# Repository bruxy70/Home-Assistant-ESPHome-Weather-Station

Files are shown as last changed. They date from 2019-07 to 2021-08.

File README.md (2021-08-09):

# Home-Assistant-ESPHome-Weather-Station
Nextion display with ESP8266 microcontroller (Wemos D1 mini) showing Home Assistant temperature sensors (temperature inside, outside and in the swiming pool) and weather forecast from the internet. But you might display any Hassio sensors, so if you wish to create own weather forecast, you can do that.

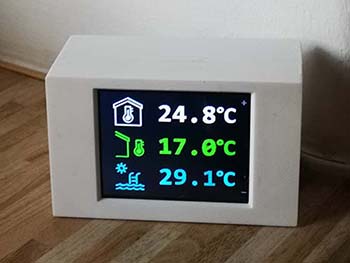
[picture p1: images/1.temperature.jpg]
Temperatures Page 1 - temperature sensors
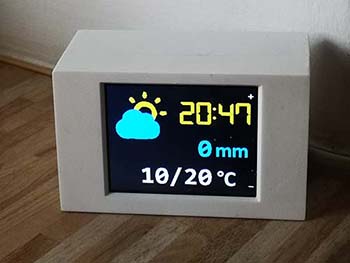
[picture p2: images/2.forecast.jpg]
Forecast Page 2 - weather forecast
  



## Getting Started

### Architecture

The Nextion display is connected via 4 wires: GND, +5V, RX, and TX. So to control the display is extremely easy - just connect these 4 wires to the corresponding ports in an Arduino board and you are set. In this project, I am using Wemos D1 mini. But in some other projects, I have the display connected to Sonoff 4ch or even Sonoff Basic (the only challenge with these is to find the pin with 5V, but this is not that hard).

### Design

The principle is very simple: I used Nextion Editor to create a layout for the display screen. There is a static image background with all graphics that do not change (including text, icons, frames, or color background). On top of the background, I created text or image objects for all the values that change. When the design is finished, you can upload the layout to the display from the NextionEditor using the serial connection (via USB FTDI board).

The program  is then very simple - it just sets the text value for the individual text objects. For example, for the inside temperature it does this:
```
it.set_component_text_printf("inside","%2.1f",id(temperature_inside).state);
```

ESPHome can read Home Assistant sensors through API, so the ESPHome sensor "teplota_uvnitr" is linked to Home Assistant sensor sensor.teplota_uvnitr this way:
```
sensor:
  - platform: homeassistant   # Inside temperature
    id: teperature_inside
    entity_id: sensor.temperature_inside
```

The weather forecast uses a picture - I have loaded set of icons through the NextionEditor, so all I do us to change the picture id this way:
```
it.send_command_printf("%s.pic=%.0f", "weather",id(today_icon).state);
```

For the ESPHome to communicate, the HMI also needs to be configured not to send responses on the commands. It is also a good idea to increase the port speed. To do that, in the Nextion Editor, in the `Program.s` tab, add these two commands before the `page` line.
```
baud=115200
bkcmd=0
```

It is using the [2.4 inch Nextion display](https://www.banggood.com/Nextion-NX3224T024-2_4-Inch-Man-machine-Interface-HMI-Screen-Kernel-In-English-p-1105052.html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).

### Additional features

There are two more "nice to have" features:
1. The display has 2 pages. I made it so it does change the page on each refresh (every 5 seconds). This is optional, you can make it either to show one page only. Or to flip the page on touching the screen (this can be easily done directly from the NextionEditor, without any programming).
2. On my Home Assistant, I also have a sensor showing whether somebody is home. When the alarm is on, nobody is home - so I am turning off the display light. And I only update the information when the display is on. This is entirely optional.
3. I also display the internet time, using ESPHome's time service.

### Source files

- **display_weather.yaml** - this is the main file - the actual ESPHome configuration
- **display.HMI** - this is the actual design of the display I use - the file can be edited via the NextionEditor (can be [downloaded](https://nextion.itead.cc/resources/download/nextion-editor/) from ITEAD pages)
- **weather.yaml** - Home Assistant configuration of the weather sensors I use. You can obviously use any sensors or any other weather service you like. Additionally, I have 3 temperature sensors - one of them is Z-Wave temperature sensor (internal). The other sensors are created through ESPHome. I also have luminosity sensor and rain sensor (but I do not show these, they are used in various automations). It is really up to you what information you find useful to show.
- **images (folder)** - I have included the source images for the Nextion display editor. These are not essential for the project, but if you want to create own design, you can start from there.
- **3D model front.stl, 3D model back.stl** - 3D model of the box the display is mounted in (Wemos D1 mini fits in the back).

## Author

* **Václav Chaloupka** - *Initial work* - [bruxy70](https://github.com/bruxy70)

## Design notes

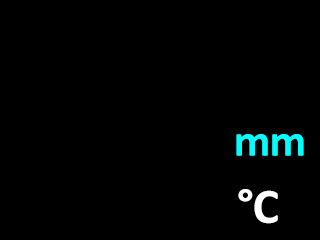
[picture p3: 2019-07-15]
images/Nextion forecast.tif

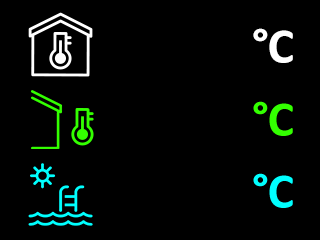
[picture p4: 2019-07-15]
images/Nextion - teplota.tif

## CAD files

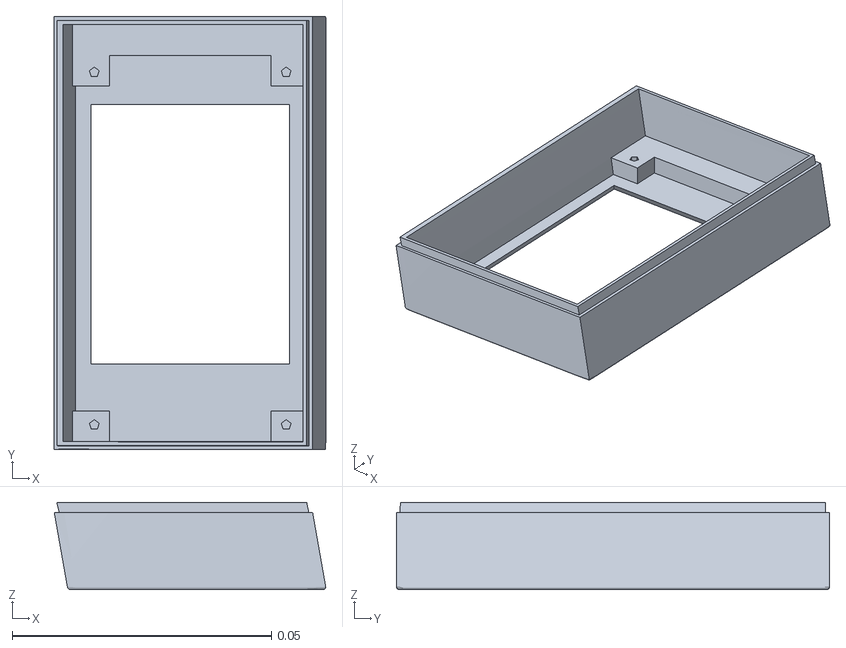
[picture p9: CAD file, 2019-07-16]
3d model src/krabicka-celo (52.4 x 83.5 x 16.8 mm).stl
0.0524 x 0.0835 x 0.0168

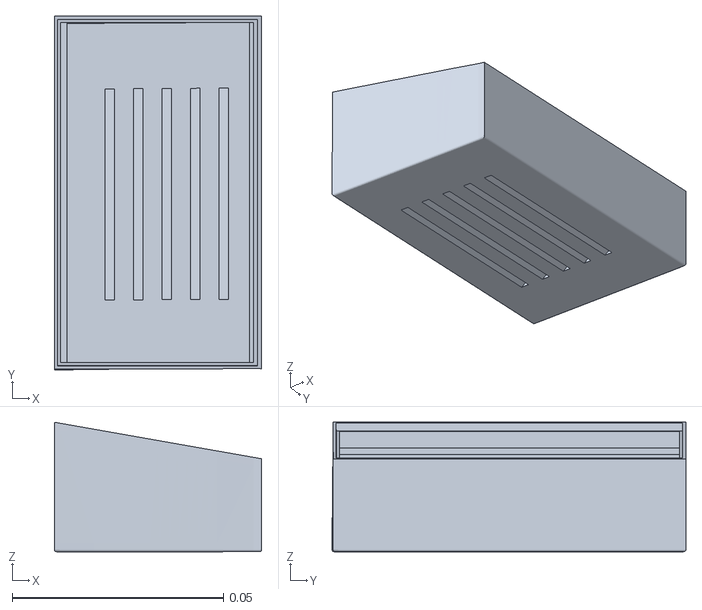
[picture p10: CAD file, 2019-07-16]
3d model src/krabicka-zada (49.1 x 83.8 x 30.7 mm).stl
0.0491 x 0.0838 x 0.0307

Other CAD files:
3d model src/display.blend

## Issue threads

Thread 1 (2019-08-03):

Waiting for ACK timed out!

gijsje, 2019-08-03:
Thank you for the creating this.
I have been playing with my nextion for a long time but am not able to get it to work with any programming.
The only thing i do get is:
```
[14:26:02][W][nextion:036]: Waiting for ACK timed out!
[14:26:02][W][nextion:083]: Sending command 'outside.txt="21.6"' failed because no ACK was received
```

I did change the pins around in the software and physical but nothing works

I am using a 5" display but that should not really care i guess
I also did try with another 2.4 display with the same thing

`# This is ESPHome configuration file. This goes to the esphome folder
# You need to provide your WiFi ssis/password and passwords for API and OTA (or put them in your esphome/secrets.yaml)
esphome:
  name: display_weather
  platform: ESP8266
  board: d1_mini_pro

wifi:
  ssid: SSID
  password: PASS
  fast_connect: true

api:
  password: PASS

ota:
  password: PASS

logger:
  baud_rate: 0     # Disable UART logging (pins GPIO1/3 are used for Nextion communication)

uart:
  rx_pin: D1
  tx_pin: D6
  baud_rate: 9600

time:
  - platform: sntp
    id: sntp_time

sensor:
  - platform: homeassistant   # Inside temperature
    id: temperature_inside
    entity_id: sensor.kantoor_temperatuur

  - platform: homeassistant   # Outside temperature
    id: temperature_outside
    entity_id: sensor.tuin_temperatuur

  - platform: homeassistant   # Swimming pool
    id: temperature_pool
    entity_id: sensor.keuken_koelkast_temperatuur

  - platform: homeassistant   # Forecast minimal temperature
    id: today_min
    entity_id: sensor.today_min

  - platform: homeassistant   # Forecast maximal temperature
    id: today_max
    entity_id: sensor.today_max

  - platform: homeassistant   # Forecast precipitation
    id: today_rain
    entity_id: sensor.today_rain

  - platform: homeassistant   # Forecast icon
    id: today_icon
    entity_id: sensor.today_icon

binary_sensor:
  - platform: homeassistant
    id: somebody_home
    entity_id: binary_sensor.kantoor_beweging

globals:
 - id: first_page             # First page of the display?
   type: bool
   restore_value: no
 - id: display_on             # Is display on?
   type: bool
   restore_value: no

display:
  - platform: nextion
    id: teplomer
    update_interval: 5s
    lambda: |-
      // Turn display on when somebody is home. Only update when display on.
      if (id(somebody_home).state) {
        if (!id(display_on)) {
          it.set_backlight_brightness(50);
          id(display_on)=true;
        }
        // Swich first/second page on each update (every 5 seconds)
        if (id(first_page)) {
          it.goto_page("forecast");
          it.send_command_printf("%s.pic=%.0f", "weather",id(today_icon).state);
          it.set_component_text_printf("minmax","%.0f/%.0f",id(today_min).state,id(today_max).state);
          if (isnan(id(today_rain).state)) {
            it.set_component_text("rain","-");
          } else {
            it.set_component_text_printf("rain","%.0f",id(today_rain).state);
          }
          auto time = id(sntp_time).now();
          it.set_component_text_printf("hour","%02d",time.hour);
          it.set_component_text_printf("minute","%02d",time.minute);
        } else {
          it.goto_page("temperature");
          it.set_component_text_printf("inside","%2.1f",id(temperature_inside).state);
          it.set_component_text_printf("outside","%2.1f",id(temperature_outside).state);
          it.set_component_text_printf("pool","%2.1f",id(temperature_pool).state);
        }
        id(first_page) = !id(first_page);  // Switch page
      } else {
        // Turn off the display if nobody is home.
        if (id(display_on)) {
          it.set_backlight_brightness(0);
          id(display_on)=false;
        }
      }`

bruxy70, 2019-08-25:
Sorry, I missed your message.

I was getting the error as well, but the display worked.
I made a change to the code not to wait for the ack.

> it.set_wait_for_ack(false);

But that won't fix your issue I think. What do you mean by "nothing works". Is the display on?
Try replacing the lambda by something simple first, such as:

lambda: |-
it.set_wait_for_ack(false);
it.set_component_text("inside","test")

What does the display show?

bruxy70, 2019-08-26:
@gijsje , BTW, you are saying that you tried with 5" display - did the Nextion Editor allow you to upload the screen I designed for 2.4" to the 5" screen?

Closed 2019-09-14.

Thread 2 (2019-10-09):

display not updating

osborne82, 2019-10-09:
hi fairly new to the nextion display so unsure if iv done this correctly
flashed d1 mini with the weather yamel no problems
loaded the hmi file into the latest  Nextion Editor and exported a .tfi file which i then flash onto the display again all good so far
now hook up the rx tx and power everything boots up and display powers up but the sensors dont get populated and doesnt flick between the two pages. only thing i can do is press the plus n minus buttons on the screen for brightness.
i added the example sensors to my configuration.yamel they show up in home assistant

i feel iv probably missed something obvious :) but stuck
thanks

bruxy70, 2019-10-09:
Hi. I think that means that the d1 mini and display do not communicate. I'd check if the RX and TX are not swapped (RX on d1 mini should go to TX on the display and vice versa), and that the pin IDs are set correctly. You can then make a simple test - e.g. in the lambda do simply it.set_component_text("inside","TEST"); to see if the communication works - this does not use any sensor data, but static text - once you get that working you can get back to the origina configuration.

osborne82, 2019-10-09:
Thanks played around some more swapping the tx n rx still nothing. I then
used a different display and bingo most of it started working. Although
temperature is saying NAN the second page does infact show time etc.
I'll keep playing but thank you for your time and the project :)

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

Closed 2019-12-05.

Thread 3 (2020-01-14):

using TFT display with spi.

wisesokol, 2020-01-14:
Is it possible to run your project on TFT with spi interface?
I wanted to make weather station by adafruit, but I liked your project more. The display I bought is TFT 2.4 spi touch.

bruxy70, 2020-01-15:
I suppose it is. If your display is supported here https://esphome.io/index.html#display-components
Or you can do that as a custom SPI device? https://esphome.io/custom/spi.html
In any case, you'd have to basically change the whole display part. If you do that, let me know, we can perhaps share that for the others.

beatagerger, 2021-02-12:
Hallo, mit Nextion und Internetwetter habe ich keine Probleme, auch verschiedene Räume kann in Nextion erstellen (Touch) aber wie verbinde ich die Räume mit der Anzeige? (viele ESP8266 mit eigenen Nextion zu eine grpße "Zentral-Display")?

bruxy70, 2021-02-12:
The display communicates with the microcontroller using UART communication - via 4 wire SPI bus - TX, RX, and 5V.

beatagerger, 2021-02-12:
Hallo bruxy,
ja.
Salon: ESP8266 Wetterstation mit Nextion 3,5 Zoll) (D4) und BME (D1 u D2) Hier auch Wettervorhersage von Openweather
Küche: ESP8266 (DHT)Temperatur/Humidity/Messior(Pflanzen)-Anzeige mit Nextion (2,8 Zoll)
Eingang: ESP8266 (BME) Messer Aussentemperatur/Hum/At
Wintergarten: ESP8266 Temperatur/Humidity-Anzeige.
Aber wie sende ich alle Daten von Küche, Wintergarten & co auf ein einziges Gerät (ESP 32 oder 8266 mit Nextion 7")?????

beatagerger, 2021-02-12:
von 3 oder 4 ESP (Pool Wasser Temperatur von Garten) Daten anzeigen auf ein anderes Gerät, ESP mit Nextion im selben WLAN?

bruxy70, 2021-02-12:
Sorry @beatagerger , I do not speak German. But from what I understand - the individual sensors will pass the temperature/humidity to Home assistant (via API, or MQTT) over WiFi. Or you can use any other sensors, like Zigbee.
Then the ESP32 or 8266 with display will read the values from Home Assistant and display them on the screen. It will not communicate directly to the sensors.

beatagerger, 2021-02-12:
Google übersetzt gut.... hi-hi-hi...
Ich bin zu blöd zu Pi und Pinguin.... Deshalb verwende ich Arduino.
Wie kann man auf ein anderes Gerät per WLAN senden?
Ich habe LED-Strip an ESP8266, diese kann auch GoogleAssistant ein/ausschalten. Aber wie leite ich Daten von einem ESP auf ein andere (ohne ESP-Server)

beatagerger, 2021-02-12:
ich kann auf Thingspeak Daten senden. Das funktioniert gut. Alle Telefonen zeigen es an. Aber der große Nextion nicht.

beatagerger, 2021-02-12:
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

Im Touch (Nextion) kann ich blättern. Das funktioniert. Nur wie mache ich es, wenn ich einen Raum anklicke, dieser Raum wird angezeigt?

beatagerger, 2021-02-12:
Jeder Raum hat seinen eigenen Sensor. Messen, Daten an Thingspeak senden, Online-Wetter (Openwether) funktioniert.
Nur das "Daten sammeln" oder auf ein andere Nextion senden, das funktioniert nicht.

beatagerger, 2021-02-12:
Ich verstehe den ESP-Home nicht.
Würde gerne verwenden, nur wie?
Muss ich etwas auf ESP8266/32 installieren? Wenn ja, was? Ich finde es nicht.
Ist das auch wie Thingspeak? Ein API?

bruxy70, 2021-02-12:
https://esphome.io/components/wifi.html
https://esphome.io/components/api.html

beatagerger, 2021-02-12:
danke.
gerade hier lese ich.
es gibt hier viele Beispiele, aber wie ich einen ESP-Home auf Android mache, finde ich nicht.
ich finde nur, wie ich einen NODEMCU dazu füge
Ist ESP-Home nur für Raspi?

bruxy70, 2021-02-12:
ESPHome is a system to control your ESP8266/ESP32 by simple yet powerful configuration files and control them remotely through Home Automation systems.
https://esphome.io/
I do not think it works for RPi. I do not have any experience with RPi, sorry.

beatagerger, 2021-02-12:
Danke.
Ich möchte keinen Raspi.
Ich weiß aber noch immer nicht welchen Code (Sketch) ich auf ESP laden soll? Und auf welcher Internetseite ist die Einrichtung?
Ich habe in Youtube auch gesucht. (wird immer MQTT gezeigt, also Raspi)
Kannst mir bitte die Internetseite schicken, wo die Einrichtung (Registrieren) erfolgt?

beatagerger, 2021-02-12:
ich habe endlich etwas gefunden.
https://www.youtube.com/watch?v=toANvJKUH3M

Wie installiert man deine Variante? Gibt es dafür einen Sketch auch?

beatagerger, 2021-02-12:
also das war auch nichts... (Server mit Telefon)
Ich hoffe, das bringt mich weiter:
https://community.home-assistant.io/t/home-assistant-community-add-on-visual-studio-code/107863

beatagerger, 2021-02-12:
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
 Endlich!!!!!!!!!!!!!!!!!!!!!!!!!!!!!!
Gefunden!
Jetzt kann ich anfangen!

bruxy70, 2021-02-12:
ESPHome is an addon to Home Assistant. If you do not have Home Assistant, you have to look for another solution.

beatagerger, 2021-02-12:
Bitte!
"Home Assistant"???????????
Alexa?
Google?
Diese kann man mit IFTT kompliiren,
Wie Home Assistant?

beatagerger, 2021-02-12:
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
 diese?

bruxy70, 2021-02-12:
If you want a solution for Alexa or Google, then buy a packaged solution that works with one of these services (they would have their logo on the packaging), and use their display. So to save you some time, you can stop looking in here and look on Amazon instead.

This repo is a DYI project, for people who like that kind of stuff. And for that HA is a great platform, since it is open. And ESPHome is Home Assistant add-on.

beatagerger, 2021-02-12:
Ich habe schon Alexa und auch Google als Assintant. IFTT hilft dabei auch ESP dazu fügen (wenn erwünscht)
Wenn aber meine Geräte und Anzeige damit nicht funktioniert, muss ich andere Lösung suchen.
Bisher war mir ESP Home nicht bekannt. Das ist für mich neu.
Ich weiß nicht,
- wie man es installiert
- wie man es verwenet
- was man damit anfangen kann
deshalb muss ich so viel lesen und experimentieren, bis es das tut, was ich will.
Alle meine Geräte, Sonoff, Tuya & CO habe ich mit Google und Alexa betrieben.

beatagerger, 2021-02-12:
Also HOME ASSINTANT lauft auch auf Android Tablet (13 Zoll)
Aber wie es dennoch auf einen Nextion anzeigt, was ich dort habe will, weiß ich immer noch nicht.............

beatagerger, 2021-02-12:
also. Wenn nicht richtig, biite um Erklärung....
ESP HOME = SERVER (wegen große Datenmengen nicht gut auf NODEMCU, sondern auf Raspi, aber es funktioniert auf ESP32)
ESP HOME ASSISTANT = Verbinden einen NODEMCU mit SERVER (HOME)

Aber!
ASSISTANT schickt Daten an HOME. (das kann man auch auf Google, oder Alexa mit IFTT) ASSISTANT = NODEMCU=Client.

Aber!
Es sollte möglich sein, in einem WLAN viele Client untereinander verbinden können (ohne HOME SERVER)

bruxy70, 2021-02-12:
Not sure I follow.

Home Assistant is an Open Source Home Automation solution. It runs on a number of platforms, including RPi, but also virtual machine or Linux Docker container.

ESPHome is an add-on to Home Assistant. I do not think you can use it without Home Assistant - it compiles the firmware for  ESP8266/ESP32 from Home Assistant, loads it to the micro-controller, and communicates with Home Assistant through Home Assistant API or MQTT.

I understand that you do not have Home Assistant. From your comments, I gather that this is too complicated for you - why should you need Home Assistant - you want to communicate with Alexa directly, or via IFTTT.

And I agree, that having Home Assistant just because of this makes no sense. I have Home Assistant as a central point of my home automation - and there are many reasons why I decided to do that, But you might have different reasons and Home Assistant might not be the best solution for you.

If this is the case, then you came to a wrong place. This solution is based on an integration with Home Assistant. If you do not have it and do not plan to have it, you are just loosing your time here. Drop it and look for other solutions. Maybe Tasmota might be the answer. I do not know, I do not really have an experience with IFTTT or direct integration of DYI solutions with Alexa. Sorry

beatagerger, 2021-02-14:
Hi,
I've been using "assistants" since Cortana, Alexa and Google were around.
I've started with automation for over 15 years, especially with Sonof, because they can operate all "assistants".
My Galusie goes up and down automatically, depending on whether the sun goes up or down. The lights, like Hue, also work great.
I have integrated an LED strip into the ESP 8266. I can also operate it on the Android (it's called "WLED")

My question was because Arduino is to be installed on Windows, but MQTT is more like Ubuntu, don't understand why this is supposed to be?
Raspi is more like Ubuntu, has nothing to do with Arduino.

Anyone can have a "Home Assistant", but in different ways.
I have a NAS, but not from Synergie, and unfortunately I still haven't found anything in years that I could run (where there is also PLEX etc.)
Running a Windows PC 24 hours a day is an exaggeration.

So I prefer Google, Alexa, and CO.
(All devices have their own server, and I just have to make sure that they are compatible with each other. For example, not only Philips lights work with HUE, and the TUYA devices can also be linked to EWELINK or SMARTHOME. ......)
From vacuum cleaner robots to pool pumps, everything runs automatically with us.

But I still haven't figured out what this client, "ESP-HOME Assistant" is for?
What should it connect to? What should it serve?

With TFFT I can also connect any Nodemcu to Google or Alexa. You only have to give a real name instead of having the router assign an IP address (set a fixed IP in the router)
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
beatagerger, 2021-02-14:
Hi,

I think, you misunderstood me.
I have smart home.
I also have 2 ladies who assist me.
I've already automated a lot.
I don't know "ESP HOME", so I read it, I just don't see the point, but maybe because I don't like Ubuntu or Raspery.

Gesendet von Mail<https://go.microsoft.com/fwlink/?LinkId=550986> für Windows 10

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

beatagerger, 2021-02-14:
I still don't know what this is, "HOME ASSISTANT"

Gesendet von Mail<https://go.microsoft.com/fwlink/?LinkId=550986> für Windows 10

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

beatagerger, 2021-02-14:
homeassistant (blue house) can be found in Android, Google Home, Alexa,
aös to install or download as "API" for ESP have not yet found ..........
In IO I only found packages. Not the API or Sketch.
I know that many people are afraid of "their data", so they prefer a server at home ...... I don't .....
I also know that with TASMOTA or chips sonoff can do a lot ...... But soldering is not really my thing, especially when such micro parts are possible .......

I once sat in a wheelchair for over a year due to an accident ... That's when I realized that it wouldn't work without automation, if, as a robot, I am sick or cannot .......
That's how I started, but it's also addicting because you always find something ......
Gesendet von Mail<https://go.microsoft.com/fwlink/?LinkId=550986> für Windows 10

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

beatagerger, 2022-08-14:
A year ago I asked a few questions, but probably because of the translation, they didn't understand me. Even then, I asked the question why "NSPanel was invented" lately.

However, just like a year ago, it wasn't about "SPI connection"

this is wrong...

It is a connection "UART" or "communication port"...

not "4-wire SPI", but "2-wire communication" (TX-RX)

So that's a little misleading...

 Just like a year ago, in "ESPHome" and NOT in Home Assistant (HA) there are still problems related to Nextion, especially "Page Display"

My situation was this:

ESP connected to sensors + display (Nextion).
All values   (value of sensors) are sent to HA via MQTT.
Today I know this is called "mqtt publish".

But the problem is from HA import to Nextion. So the query, as "client".

A year ago I was shown how it works with NodeRed. Not in ESPHome...

In Home Assistant, but with the help of NodeRed.

ESPHome (I already know that today) is a replacement for ArduinoIDE, or EasyESP, nothing else, it's like "ESP-Flash"...

It's a pity that nobody could explain it to me back then... By the way, I still don't use ESPHome to this day because it just "bitters way too much". I've stuck with IDE, or EasyESP, to this day

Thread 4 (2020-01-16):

Display not showing any values

lucky79, 2020-01-16:
Hi there,

I've built the device, but the display is not showing any value unfortunately. I don't know where the problem can be. I have similar setup to you, the homeassistant sensors values are being shown on ESPHome Log with the display connected, pins correctly set, but still no values on the display. Right now using the same lambda as you, but getting weird warning during compilation:

Compiling /data/meteo1/.pioenvs/meteo1/src/main.cpp.o
src/main.cpp:255:3: warning: multi-line comment [-Wcomment]
   //   lambda: !lambda " Do not wait for ack (this delays the whole procedure a lot, and\
   ^

Anyway I tried such simple lambda like this:
it.set_wait_for_ack(false);
it.set_component_text_printf("inside","%2.1f",id(temperature_inside).state);

which doesn't show any warning during compilation, but inside temperature is not shown anyway

[15:38:06][C][sntp:043]: SNTP Time:
[15:38:06][C][sntp:044]:   Server 1: '0.pool.ntp.org'
[15:38:06][C][sntp:045]:   Server 2: '1.pool.ntp.org'
[15:38:06][C][sntp:046]:   Server 3: '2.pool.ntp.org'
[15:38:06][C][sntp:047]:   Timezone: 'CET-1CEST-2,M3.5.0/2,M10.4.0/3'
[15:38:06][C][homeassistant.binary_sensor:032]: Homeassistant Binary Sensor 'somebody_home'
[15:38:06][C][homeassistant.binary_sensor:033]:   Entity ID: 'binary_sensor.somebody_home'
[15:38:06][C][homeassistant.sensor:024]: Homeassistant Sensor 'sun_elevation'
[15:38:06][C][homeassistant.sensor:024]:   Unit of Measurement: ''
[15:38:06][C][homeassistant.sensor:024]:   Accuracy Decimals: 1
[15:38:06][C][homeassistant.sensor:025]:   Entity ID: 'sensor.sun_elevation'
[15:38:06][C][homeassistant.sensor:024]: Homeassistant Sensor 'temperature_inside'
[15:38:06][C][homeassistant.sensor:024]:   Unit of Measurement: ''
[15:38:06][C][homeassistant.sensor:024]:   Accuracy Decimals: 1
[15:38:06][C][homeassistant.sensor:025]:   Entity ID: 'sensor.teplota_loznice'
[15:38:06][C][homeassistant.sensor:024]: Homeassistant Sensor 'temperature_outside'
[15:38:06][C][homeassistant.sensor:024]:   Unit of Measurement: ''
[15:38:06][C][homeassistant.sensor:024]:   Accuracy Decimals: 1
[15:38:06][C][homeassistant.sensor:025]:   Entity ID: 'sensor.temperature_outside'
[15:38:06][C][homeassistant.sensor:024]: Homeassistant Sensor 'temperature_pool'
[15:38:06][C][homeassistant.sensor:024]:   Unit of Measurement: ''
[15:38:06][C][homeassistant.sensor:024]:   Accuracy Decimals: 1
[15:38:06][C][homeassistant.sensor:025]:   Entity ID: 'sensor.temperature_pool'
[15:38:06][C][homeassistant.sensor:024]: Homeassistant Sensor 'today_min'
[15:38:06][C][homeassistant.sensor:024]:   Unit of Measurement: ''
[15:38:06][C][homeassistant.sensor:024]:   Accuracy Decimals: 1
[15:38:06][C][homeassistant.sensor:025]:   Entity ID: 'sensor.today_min'
[15:38:06][C][homeassistant.sensor:024]: Homeassistant Sensor 'today_max'
[15:38:06][C][homeassistant.sensor:024]:   Unit of Measurement: ''
[15:38:06][C][homeassistant.sensor:024]:   Accuracy Decimals: 1
[15:38:06][C][homeassistant.sensor:025]:   Entity ID: 'sensor.today_max'
[15:38:06][C][homeassistant.sensor:024]: Homeassistant Sensor 'today_rain'
[15:38:06][C][homeassistant.sensor:024]:   Unit of Measurement: ''
[15:38:06][C][homeassistant.sensor:024]:   Accuracy Decimals: 1
[15:38:06][C][homeassistant.sensor:025]:   Entity ID: 'sensor.today_rain'
[15:38:06][C][homeassistant.sensor:024]: Homeassistant Sensor 'today_icon'
[15:38:06][C][homeassistant.sensor:024]:   Unit of Measurement: ''
[15:38:06][C][homeassistant.sensor:024]:   Accuracy Decimals: 1
[15:38:06][C][homeassistant.sensor:025]:   Entity ID: 'sensor.today_icon'
[15:38:09][D][api.connection:583]: Client 'Home Assistant 0.104.0 (10.10.110.35)' connected successfully!
[15:38:09][D][sntp:059]: Synchronized time: Thu Jan 16 15:38:09 2020
[15:38:10][D][homeassistant.binary_sensor:021]: 'binary_sensor.somebody_home': Got state ON
[15:38:10][D][binary_sensor:034]: 'somebody_home': Sending initial state ON
[15:38:10][D][homeassistant.sensor:019]: 'sensor.teplota_loznice': Got state 21.60
[15:38:10][D][sensor:092]: 'temperature_inside': Sending state 21.60000  with 1 decimals of accuracy
[15:38:10][D][homeassistant.sensor:019]: 'sensor.today_min': Got state -3.10
[15:38:10][D][sensor:092]: 'today_min': Sending state -3.10000  with 1 decimals of accuracy
[15:38:10][D][homeassistant.sensor:019]: 'sensor.today_max': Got state 7.50
[15:38:10][D][sensor:092]: 'today_max': Sending state 7.50000  with 1 decimals of accuracy
[15:38:10][D][homeassistant.sensor:019]: 'sensor.today_rain': Got state 0.10
[15:38:10][D][sensor:092]: 'today_rain': Sending state 0.10000  with 1 decimals of accuracy
[15:38:10][D][homeassistant.sensor:019]: 'sensor.today_icon': Got state 8.00
[15:38:10][D][sensor:092]: 'today_icon': Sending state 8.00000  with 1 decimals of accuracy

lucky79, 2020-01-16:
Ok never mind, I read the closed issue, I had swapped the RX/TX and it works now. Sorry

Closed 2020-01-16.

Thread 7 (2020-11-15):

[Question] temperature icons

pniewiadowski, 2020-11-15:
Hi Vaclav,

first of all thank you very much for this project. I made one for me too, and I used the 3d print model - fits perfectly.

But since, I don't have a pool I would like to put there other measurement and here is the question: from where you took the icons?
I would like to find one with similar look for the other measurement (it will be humidity actually).

PS. I am watching your YT videos. Keep it up!
Greetings from Poland.

bruxy70, 2020-11-15:
Hi,
I made them in Inkscape, based on some template. So I am afraid you won't find their siblings.
Greetings to Poland :).

pniewiadowski, 2020-11-16:
I found it.
If anybody will be looking for some of the icons in the same style, you can find it here:
https://www.visualpharm.com/free-icons/temperature%20inside-595b40b85ba036ed117db483

Closed 2020-11-15.

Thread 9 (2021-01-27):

Display don´t show any values

Mikro007, 2021-01-27:
Hi!
I followed your guide 100% but I dont get the display to show values from sensors, it just shows the first picture and not changes pictures eather.

What do I wrong?

bruxy70, 2021-01-27:
Hard to say. Probably the board does not communicate with the display. My recommendation is to study ESPHome, experiment, have fun with it, be patient, take it easy. You have to configure the serial configuration, the correct GPIO ports, make sure you connect RX to TX and TX to RX. That the speed is configured  correctly. Start from basics, try to set static values (constants, static text or number). Once this works connect that back to HA API.

Mikro007, 2021-01-28:
It was just wrong connection with TX/RX. TX from display will go to RX on Wemos. RX from display will go to TX on Wemos.
When display is black, wait for it to respond again to get the values.

Closed 2021-01-28.

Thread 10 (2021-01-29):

lost completely

commentsonly, 2021-01-29:
watched some of your videos aswell as trying to understand the code.
Even no problem with the GUI editor from nextion.
But what's missing is another 5min to your videos about the HOW TO integrate things with HA.
A simply .. this should go there .. isn't enough information.
Same applies to the HMI file. I'm lost guessing if this must be warped into the display onto an SD bumped into the displays SD card slot or simply should sit inside a HA ESPhome project.
Since so, thanks for spreading the word and videos about that things should work as expexted but it's still a miracle to me about how to get these things together. Looks to me as if I did understand if ever 10% of all steps one has to do.
Perhaps you could do another video showing the step by step about where to place each single file from here into which target, let if be ESPhome or HA.

bruxy70, 2021-01-29:
This repository is for [this video](https://youtu.be/_u1sOCfyghY). Sorry, can't do better than that.

commentsonly, 2021-01-29:
Don't get me wrong I appreciated exactly that video a lot. It was the first one I stumbled across.
As said earlier, what I do miss is likely the steps poeple more familar with HA won't need a second to think about.
but I'm a step further now ... from the ESPhome docs I see that the HMI has to go onto the SD inserted into the display.
Might take some some weeks until I found out everything all others already know about.
And finally ..... thanks for the damn fast response, I didn't expect you acting that fast.

commentsonly, 2021-02-03:
getting closer to a solution, just wanted to let you know. :-) issue in the begining, my old USB=TTL=adapter was the problem. While being able to use if flashing gosund plugs and such like, it never made it. Not to mention the nextion refused most of my microSD cards. With a newly bough USB=TTL=adapter it works to flash the device.
And I'm also also able to blow values into the textboxes.
But I failed to work out about how to blow sensor values onto the device. I got confused with all these terms, id, entitly_id, and so on. I assumed the entitly_id must be the one from HA but tuning on logging does show these remain empty which explains why the display textboxes show 'nan' all the time.
I thought that I could simply make use of what HA lists from within settings entities entity-id. Am I wrong here?

bruxy70, 2021-02-03:
Hi. I actually never tried to use the SD card with the Nextion. I think what you ask is described in the Esphome documentation. It worked for me quite smoothly, if that doe snot work for you, I suggest asking this to the Esphome support, I am not really expert in this. Sorry.

commentsonly, 2021-02-03:
as said I bypassed this SD card issue by now using a new USB-TTL-adapter.
All I got stuck is that I can't get any sensor values sent to the nextion.
in short
it.set_component_text("objectname","1234"); does work while using an id linked to an entity_id availalbe within homeassistant simply results in '' (nothing).
Means it's surely not an issue between the nextion and the esp connected to it, but more something to do with
"  - platform homeassistant" which I never came across right now. I was assuming that if I got an esp linked to Ha with a BME280 sensor ending up with a temperaturesensor resulting in esp8266_outside_temp ..... it should be fine to use that entity_id with the sensor: - platform: homeassistant
  id: esp8266_outside_temp
  entity_id: sensor.esp8266_outside_temp
but I might have been wrong here. The sensor does show values if looking at developper in HA were all the current values are shown besides all entities, but when logging what happens in esphome with logging turned on the result is simply ''.
And if nothing reaches the esp connected to the nextion the nextion won't display anything but 'nan'.

commentsonly, 2021-02-04:
Oh my god ...... got it running, my fault.
I mixed up "Home Assistant" with "Home Automation", means I forgot about 1 small step for the noob but a big step to make you guideline 100% working against 100% failing.
If one flashes an ESP from with ESPhome fired up from within HA there's automation in terms of integrating the new ESP into HA. And since so the new ESP won't see any HA entities at all, resulting in '' with then leads to 'nan'. That simple.
Found an article that indicated I wasn't the first who suffered from that issue.
Perhaps a simple 1-liner not at the ned "don't forget about..." would have made things lots easier.

Nevertheless ... great work from your side with the descriptions.

Closed 2021-01-29.

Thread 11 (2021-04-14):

no ACK was received

projectdimpreza, 2021-04-14:
Im tried to copy your weather station.. and i would like a button on the nextion display to show the real world state on a light.. when it is press on the physical switch.. when its ON then the button on the nextion display would change too... i made the nextion display button to turn ON or OFF the light.. but i had no luck in changing its actual state if i turn the light ON using the physical switch... i shows OFF on the nextion display button.. and i have a error log on esphome like this...

Sending command 'lightlamp.pic = 1' failed because no ACK was received

here is part of my esphome config..

display:
  - platform: nextion
    id: lightdisplay
    update_interval: 5s
    lambda: |-
      if (id (light_status) .state) {
         it.send_command_printf ("lightlamp.pic = 1");
      } else {
         it.send_command_printf ("lightlamp.pic = 0");
      }

Do you know what am i missing here? thanks !

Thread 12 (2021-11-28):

nextion  display is not working after network disconnect

asafmatan, 2021-11-28:
Hello there.

I have cloned your project successfully with all the hmi/code uptodate changes with esphome 2021.11.1 and nov home assistant as well.

The phenomena I'm facing is that after a sudden network disconnect esphome is able to connect again to the nodemcu but it seems that display lambda loop is not running anymore.

INFO nextion_test.local: Ping timed out!
INFO Disconnected from ESPHome API for nextion_test.local
WARNING Disconnected from API
INFO Successfully connected to nextion_test.local
[17:45:55][D][sntp:075]: Synchronized time: 2021-11-28 17:45:55
[17:45:56][D][api:098]: Accepted 192.168.86.80
[17:45:56][D][api.connection:747]: Home Assistant 2021.11.5 (192.168.86.80): Connected successfully
[17:45:56][D][homeassistant.sensor:024]: 'sensor.temperature_158d00022266cc': Got state 23.20
[17:45:57][D][sensor:113]: 'temperature_outside': Sending state 23.20000  with 1 decimals of accuracy

Is this phenomena familiar to you? can you tell how to restart both nextion and esp processor in case of network reconnect and get back to the display loop?

Regards
Asaf

bruxy70, 2021-11-29:
No, it does not happen this any of my ESPHome devices. I'd check on the ESPHome discord if it ever happened to anyone.

Closed 2021-11-29.

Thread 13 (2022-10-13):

problem UART comunication

marcazzan, 2022-10-13:
Hi I'm testing your weather station with an esp d1 mini and a 3.5 inch nexion display, I loaded the yaml on esp home and everything works, the data updates, but uart doesn't communicate between nexion and d1 mini? what can it be?

bruxy70, 2022-10-13:
I'd check that the wires are connected correctly (TX to RX and RX to TX). That the speed is set the same in Nextion Editor and ESPHome. If this does not work, I'd try to add a PR that was fixing an error in communication (I think this one should be already included in the ESPHome release, but you can try)

```yaml
external_components:
  - source: github://pr#3657
    components: [ nextion ]
```

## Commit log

2019-07-24 initial upload
    [display.blend, krabicka-celo (52.4 x 83.5 x 16.8 mm).stl, krabicka-zada (49.1 x 83.8 x 30.7 mm).stl]
2020-06-28 Create ABB Time.stl
